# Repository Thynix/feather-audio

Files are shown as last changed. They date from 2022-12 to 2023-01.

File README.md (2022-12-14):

# feather-audio

Interactive MP3 player for Adafruit Feather and PlatformIO.

Screen shows song tags, time elapsed, and playlist position. Songs are in
sorted into lexicographic order from the root of the MicroSD card. Uses an
encoder for song control, and potentiometer for volume.

## Hardware

* Encoder - https://www.adafruit.com/product/4991
* Potentiometer - https://www.adafruit.com/product/3391 or similar
* OLED 128x64 - https://www.adafruit.com/product/2900
* Feather M4 Express - https://www.adafruit.com/product/3857
* Music Maker FeatherWing - https://www.adafruit.com/product/3436 or https://www.adafruit.com/product/3357

Optional:

### Solar / Lithium Ion Polymer Charger - https://www.adafruit.com/product/4755

Easier portability between battery, solar power, and more easily accessible USB
port for power.

### Tactile button - https://www.adafruit.com/product/1119 or similar

Pulling pin 12 to ground stops playback and enters mass storage mode to offer
the MicroSD card over USB. This is extremely slow, but avoids the need to
remove the card and offers status information to make it more bearable.

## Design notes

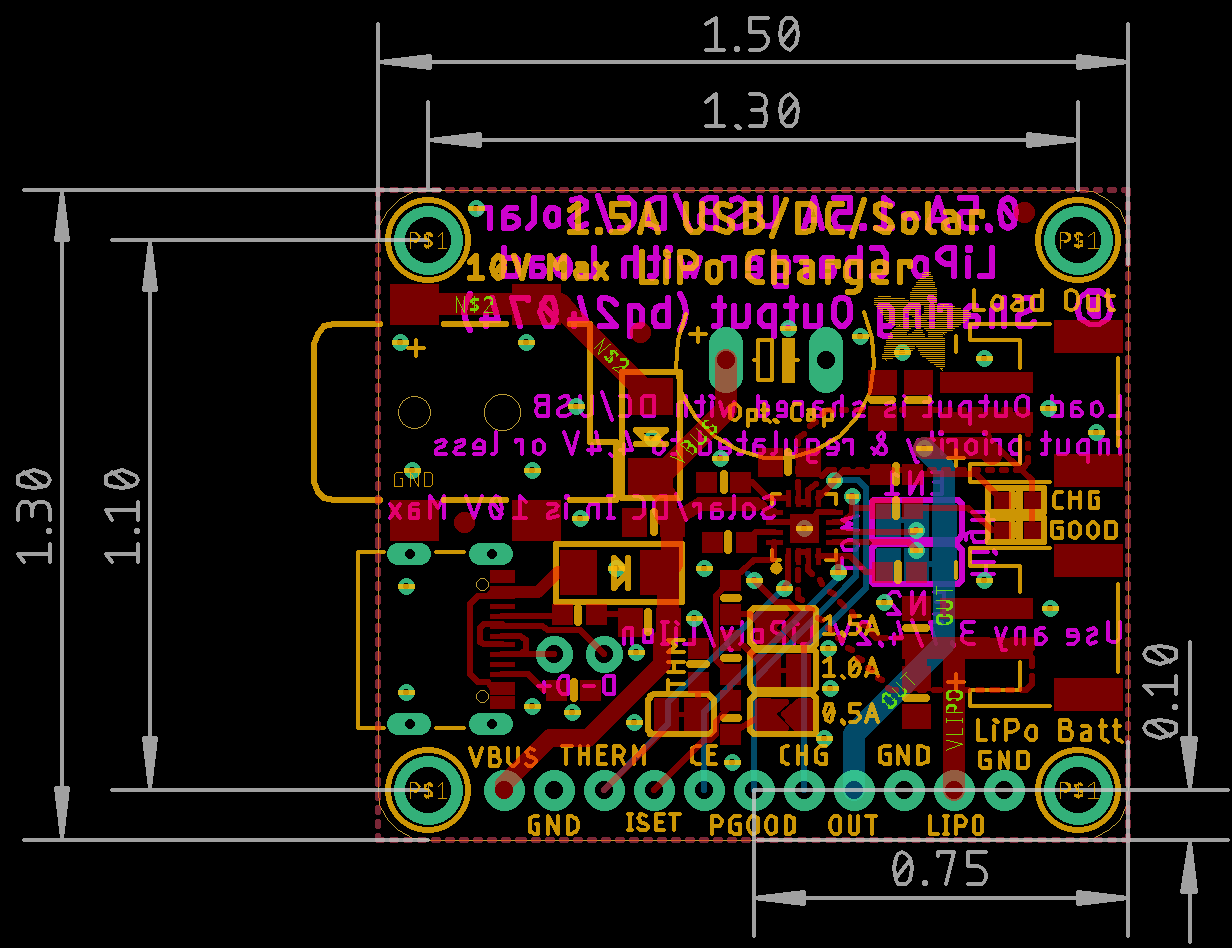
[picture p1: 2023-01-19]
case/charging_board_diagram.png

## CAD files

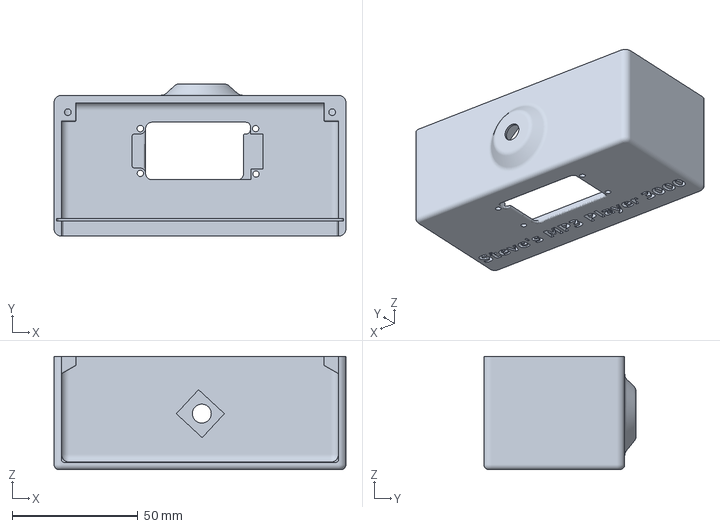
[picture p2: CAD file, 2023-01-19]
case/Body-v85.3mf
116.0 x 60.6 x 45.0 mm

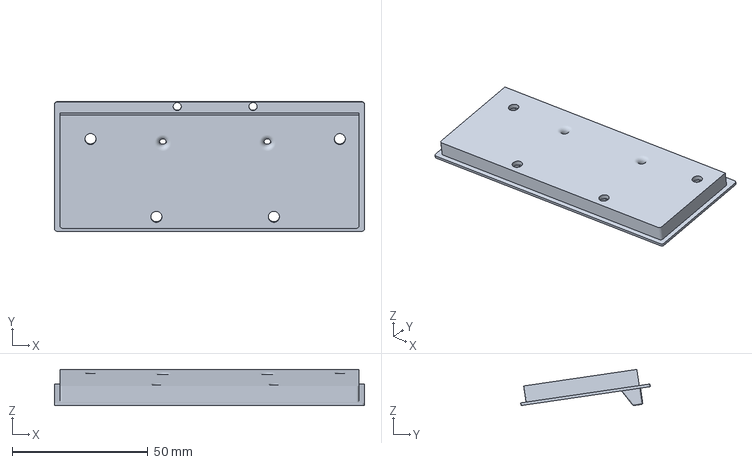
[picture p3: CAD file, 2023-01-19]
case/Bottom-v85.3mf
114.0 x 47.7 x 13.3 mm

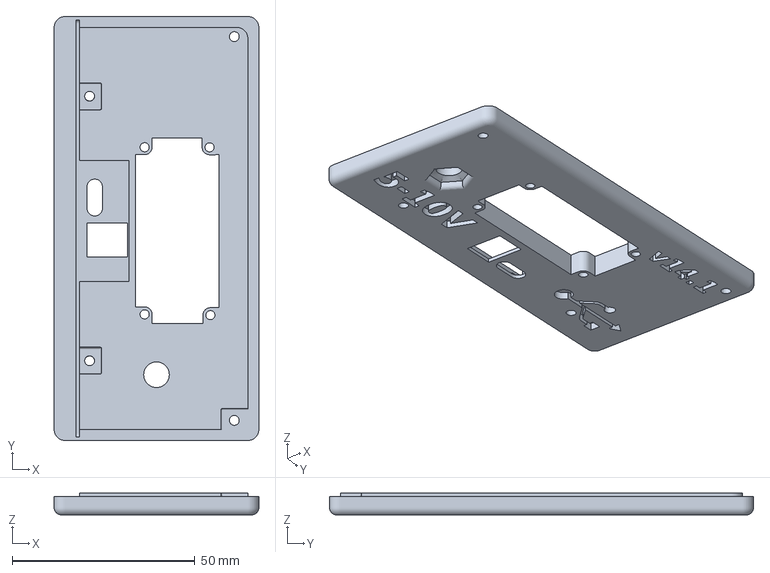
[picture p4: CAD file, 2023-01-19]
case/Back-v85.3mf
56.0 x 116.0 x 6.00 mm

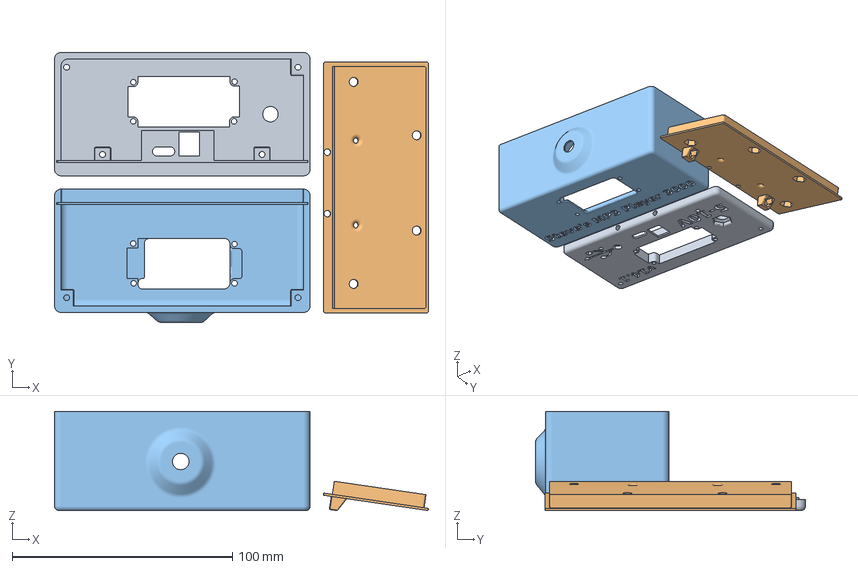
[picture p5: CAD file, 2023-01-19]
case/v85.3mf
169.7 x 122.6 x 45.0 mm
Back-v85
Bottom-v85
Body-v85

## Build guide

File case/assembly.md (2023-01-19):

## Assembly Notes

1. Put the encoder in before anything else because the OLED board pins would block it otherwise.
2. Put right transducer's wires (it's on the left when viewed from the back as when connecting it) in the bottom terminal blocks on the MusicMaker because they have farther to go to reach the terminal blocks.
2. Don't completely tighten the outer transducer screws until the bottom is seated into the body because they're liable to exceed the bottom and intrude on/push the body. Once it's seated it may be okay to tighten.

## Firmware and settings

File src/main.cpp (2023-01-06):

#include <constants.h>
#include <display.h>
#include <encoder.h>
#include <led.h>
#include <mass_storage.h>
#include <vs1053.h>

#include <Adafruit_SleepyDog.h>
#include <Arduino.h>
#include <Wire.h>
#include <algorithm>

// Updating the display is usually at or just under this duration.
const unsigned long target_frametime_micros = 70000;

// Blink codes for startup situations
const int waiting_for_serial[] = {short_blink_ms, 0};

void setup()
{
  auto start = micros();
  mass_storage_setup();

  Serial.begin(9600);

  // This might not succeed, but it's worth a shot to have better startup feedback before serial.
  display_setup();
  display_text("Hello there", booting);

  vs1053_setup();

#if 0
  // Blink while waiting for serial connection
  if (!Serial) {
    display_text("Waiting for      serial", "");

    while (!Serial) led_blinkCode(waiting_for_serial);
  }

  Serial.println("Starting up");
#endif

  // First attempts didn't retry until success; try harder to make sure it's ready.
  while (!display_setup())
    Serial.println("Display setup failed");

  while (!vs1053_setup())
    Serial.println("VS1053 setup failed");

  while (!encoder_setup())
    Serial.println("Cannot find encoder");

  vs1053_loadSongs();

  // Enable watchdog before entering loop()
  int countdown_milliseconds = Watchdog.enable(4000);
  Serial.print("Watchdog timer set for ");
  Serial.print(countdown_milliseconds);
  Serial.println(" milliseconds");

  Serial.print("Startup completed in ");
  Serial.print((micros() - start) / 1000);
  Serial.println(" milliseconds");

  led_off();
  encoder_led_off();

  // Start the first song.
  vs1053_changeSong(0);
}

void loop()
{
  static unsigned long frame_times[2000] = {};
  static int frame_time_index = 0;
  static unsigned long idle_frame_times[2000] = {};
  static int idle_frame_time_index = 0;
  const unsigned long frame_time_report_interval_ms = 5000;
  static unsigned long last_frame_time_report;
  static bool paused = false;

  unsigned long start_micros = micros();
  unsigned long start = millis();

  Watchdog.reset();

  // Switch to mass storage mode on button press. This is a separate mode so
  // that music playback isn't interrupted by mass storage CPU load.
  // mass_storage_mode() does not return; a second button press resets the board.
  if (mass_storage_button()) {
    vs1053_pause(true);
    mass_storage_mode();
  }

  // Toggle pause on encoder button press.
  // Ignore encoder movement while the knob switch is changing - the position
  // can become unstable.
  if (encoder_togglePause()) {
    paused = !paused;
    vs1053_pause(paused);
  } else {
    auto change = encoder_getChange();
    if (!paused && change != 0)
      vs1053_changeSong(change);
  }

  bool display_updated = vs1053_loop();

  Serial.flush();

  unsigned long end = millis();
  unsigned long frame_time = end - start;
  bool interval_report = end - last_frame_time_report >= frame_time_report_interval_ms;
  bool buffer_full = frame_time_index == COUNT_OF(frame_times);
  bool idle_buffer_full = idle_frame_time_index == COUNT_OF(idle_frame_times);
  if (interval_report) {
    unsigned long total = 0;
    unsigned long max_display = 0;
    for (int i = 0; i < frame_time_index; i++) {
      total += frame_times[i];
      if (frame_times[i] > max_display) max_display = frame_times[i];
    }

    unsigned long idle_total = 0;
    unsigned long max_idle = 0;
    for (int i = 0; i < idle_frame_time_index; i++) {
      idle_total += idle_frame_times[i];
      if (idle_frame_times[i] > max_idle) max_idle = idle_frame_times[i];
    }

    char buf[512];
    snprintf(buf, sizeof(buf), "DISPLAY mean %02.1f ms, max %02lu ms | IDLE %02.1f ms, max %02lu ms \r\n",
             total / max((float)frame_time_index, 1.0f),
             max_display,
             idle_total / max((float)idle_frame_time_index, 1.0f),
             max_idle);

    last_frame_time_report = end;

    // Don't reconsider the same collection of frame times.
    buffer_full = true;
    idle_buffer_full = true;
  }

  if (buffer_full) frame_time_index = 0;
  if (idle_buffer_full) frame_time_index = 0;

  // Present averages only of display update duration
  if (display_updated) frame_times[frame_time_index++] = frame_time;
  else idle_frame_times[idle_frame_time_index++] = frame_time;

  // If this frame completed faster than the target, wait before starting the
  // next.
  auto micros_frame_time = micros() - start_micros;
  if (micros_frame_time < target_frametime_micros) {
    delayMicroseconds(target_frametime_micros - micros_frame_time);
  } else {
    Serial.printf("Long frame! %lu us\r\n", micros_frame_time);
  }
}

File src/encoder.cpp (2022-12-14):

#include <encoder.h>

#include <constants.h>
#include <display.h>
#include <led.h>

#include <Debouncer.h>
#include <Adafruit_seesaw.h>
#include <seesaw_neopixel.h>

const uint8_t seesaw_addr = 0x36;
const uint8_t seesaw_switch_pin = 24;

const int no_seesaw[] = {long_blink_ms, 0};
const int wrong_seesaw[] = {long_blink_ms, short_blink_ms, 0};

Adafruit_seesaw ss;
seesaw_NeoPixel sspixel = seesaw_NeoPixel(1);

int32_t encoder_position;

Debouncer encoderButton(debounce_ms);

bool encoder_setup()
{
    // Search for Seesaw device
  if (!ss.begin(seesaw_addr) || !sspixel.begin(seesaw_addr)) {
    display_text("Cannot find encoder", boot_error);
    led_blinkCode(no_seesaw);
    return false;
  }

  // Check that found device is a rotary encoder
  uint32_t version = ((ss.getVersion() >> 16) & 0xFFFF);
  if (version  != 4991) {
    Serial.print("Wrong firmware loaded? Instead of rotary encoder, found product #");
    Serial.println(version);

    display_text("Wrong encoder version", boot_error);
    while(true) led_blinkCode(wrong_seesaw);
  }

  // Set encoder pixel green while booting
  sspixel.setPixelColor(0, 0x00ff00);
  sspixel.show();

  // Use a pin for the built in encoder switch
  ss.pinMode(seesaw_switch_pin, INPUT_PULLUP);

  // Get starting position
  encoder_position = ss.getEncoderPosition();

  ss.setGPIOInterrupts((uint32_t)1 << seesaw_switch_pin, 1);
  ss.enableEncoderInterrupt();

  return true;
}

bool encoder_togglePause()
{
  static bool paused = false;

  if (!(encoderButton.update(ss.digitalRead(seesaw_switch_pin)) && !encoderButton.get()))
    return false;

  paused = !paused;

  // Red if paused, and off if not.
  if (paused) {
    sspixel.setPixelColor(0, 0xff0000);
    sspixel.show();
  } else {
    encoder_led_off();
  }

  return true;
}

int encoder_getChange()
{
  auto new_position = ss.getEncoderPosition();
  auto encoder_change = new_position - encoder_position;
  encoder_position = new_position;

  return encoder_change;
}

void encoder_led_off()
{
  sspixel.setPixelColor(0, 0x000000);
  sspixel.show();
}

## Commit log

2022-12-14 Explain ignoring encoder position
2022-12-14 Add tag reading debug printing
2022-12-14 Add missing display operations module
    [display.cpp]
2022-12-14 Fix song change ordering strangeness on startup; average volume pin reads for stability
2022-12-14 Use more volume samples
    This avoids noise better and there's a lot of frame time headroom.
    Currently ~7 ms with target of at most ~16 ms.
2022-12-14 Prevent display line overflow
    [display.cpp]
2022-12-14 Scroll text when lines are too long
    [display.cpp]
2022-12-14 Log long frame times
2022-12-14 Replace buffer allocation with fixed buffers in display_text()
    [display.cpp]
2022-12-14 Polish bootup behavior
    * Write "Booting..." consistently while still booting
    * Write to display while waiting for serial
    * Shorten blink codes - this required reversing odd/even on/off so that
    a single-entry code isn't off all the time between the zero-index
    intial value and staying off after the sequence.
    * Check for display initialization failure.
    * Move #defines into typed variables.
    * Avoid manually specifying NeoPixel values that match defaults.
    [display.cpp]
2022-12-14 Scroll lines more smoothly - by pixel, not character
    This could be improved by disabling text wrapping and having following
    lines also shifted by the same amount. Currently only the first line
    scrolls smoothly - the rest are still per-character, and the last
    character isn't displayed on it until it has enough room to fit
    completely.
2022-12-14 Give button input more time to settle before read in waitForSerial()
2022-12-14 On display failure, repeatedly print to serial
    Other failures later in setup() get to write to the screen and to wait
    for serial.
2022-12-14 Remove figured out TODO
    This was scrolling by 2 pixels because I forgot that this display is
    damaged and many columns are missing every other one. So smooth
    scrolling in one area makes for artifacts in the other.
    [display.cpp]
2022-12-14 Run scrolling at 60 FPS; avoid truncation in scrolling decision
    [display.cpp]
2022-12-14 Log average display update frame times; set 25 FPS target
2022-12-14 Avoid unnecessary wrapping; hold at end when all overflow displayed
    [display.cpp]
2022-12-14 Fix waiting for serial by removing A button requirement
    Guessing it never settled before the check.
2022-12-14 Overclock to 200 MHz
    Hopefully this can lower loading and frame times? Seems good to try at
    least.
2022-12-14 Report average idle frame time; fix divide by 0.0
2022-12-14 Switch to TinyUSB
    This will allow exposing the MicroSD card as mass storage.
2022-12-14 Log max frame time per category
    Increase length of frame time buffer to hopefully include everything
    between updates.
2022-12-14 Move global config out of board-specific config
2022-12-14 Print song loading progress
    With more songs it gets to take a while, so showing progress is good.
2022-12-14 Fix scrolling bounds detection
    I don't know what that was even supposed to do before.
    [display.cpp]
2022-12-14 Disable VS1053 interrupts; use micros for frame delay
2022-12-14 Put mass storage behind a mode switch button
    Also feeds the buffer while waiting for the next frame.
2022-12-14 Use median of more volume pot samples
2022-12-14 Fix missing ' after display name Serial print on song change
    Serial.printf() might have a length limit
2022-12-14 Break apart into modules
    Known bug: pausing corrupts song seconds played somehow.
    [display.cpp, encoder.cpp, mass_storage.cpp]
2022-12-14 Poll mass storage button on timer; add animation
2022-12-14 Switch back to filling buffer with interrupts
    This avoids complexity, and seems preferable if it can be stable.
    [vs1053.cpp, vs1053.h]
2022-12-14 Move mass storage button to mass storage module
2022-12-15 Improve volume level stability
    [vs1053.cpp]
2022-12-15 Ignore single-digit volume flicker unless actively changing
    This avoids flickering between values when at a boundary.
    [vs1053.cpp]
2022-12-16 Use decode time for song seconds elapsed
    Avoids the need to fix whatever was going on with pause time.
    [vs1053.cpp]
2022-12-16 Add example-based simple player for crash testing
    [vs1053_test.ino]
2022-12-16 Polish Arduino test; boot count log is broken
    [vs1053_test.ino]
2022-12-17 Add neopixel fades on error; change song on encoder
    [vs1053_test.ino]
2022-12-17 Fix encoder click
2023-01-02 Beep when blink code has LED on
2023-01-04 Check for encoder before loading songs
    If loading songs requires importing instead of loading the cache, this
    can take several seconds. First check whether the encoder - the last
    piece of hardware - is present.
2023-01-04 Fix cache breakage by skipping names with newlines
    [vs1053.cpp]
2023-01-04 Use polling for mass storage button; reset on second press
    The timer thing wasn't working for unclear reasons, and there's a new
    debouncer library. (It doesn't support providing values though, so the
    old one is still here too for the encoder switch.)
    [main.cpp, mass_storage.cpp]
2023-01-06 Fix test sketch debouncing
    [vs1053_test.ino]
2023-01-06 Import files while iterating
    This also fixed a hang that developed that I don't understand.
    [vs1053.cpp]
2023-01-06 Remove needless Wire.begin()
    Why was this here?
2023-01-09 Truncate 2 bits of noise from volume reading
    Hopefully in addition to lots of samples this will reduce volume jitter.
    [vs1053.cpp]
2023-01-19 Add case design
    [Back-v85.3mf, Body-v85.3mf, Bottom-v85.3mf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]
2023-01-19 Reduce volume knob noise and fix not reading at startup
    [vs1053.cpp]
